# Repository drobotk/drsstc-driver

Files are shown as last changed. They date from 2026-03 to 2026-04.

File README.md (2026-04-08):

# DRSSTC driver

This is a KiCad project of the DRSSTC driver used in my tesla coil.

# Features:
- Single CT input for both clock and overcurrent detection
- Phase lead adjustable with a potentiometer, no need for a tunable inductor
- Adjustable self-oscillation, useful for testing and running a coil at the upper pole frequency
- Traditional / pulse skipping operation selectable with a jumper
- Adjustable UVLO for protecting precious IGBTs
- 74AHC high speed logic, less phase lead needed
- More modern parts than a UD2.7c

# Credits
As with most DRSSTC drivers, this one is based on previous work of many people (Steve Ward, Finn Hammer, Philip Slawinski, Bart Anderson, Eric Goodchild, Gao Guangyan, etc.). The design I took the most inspiration from is [this](https://highvoltageforum.net/index.php?topic=2054.0) project by [Mike](https://highvoltageforum.net/index.php?action=profile;u=1209) on HVF.

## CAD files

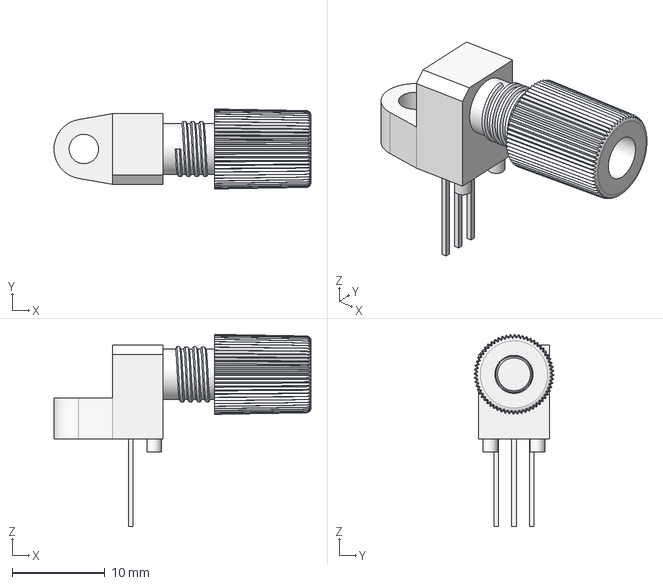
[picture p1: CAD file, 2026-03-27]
IF-D95T.stp
27.7 x 8.64 x 20.8 mm

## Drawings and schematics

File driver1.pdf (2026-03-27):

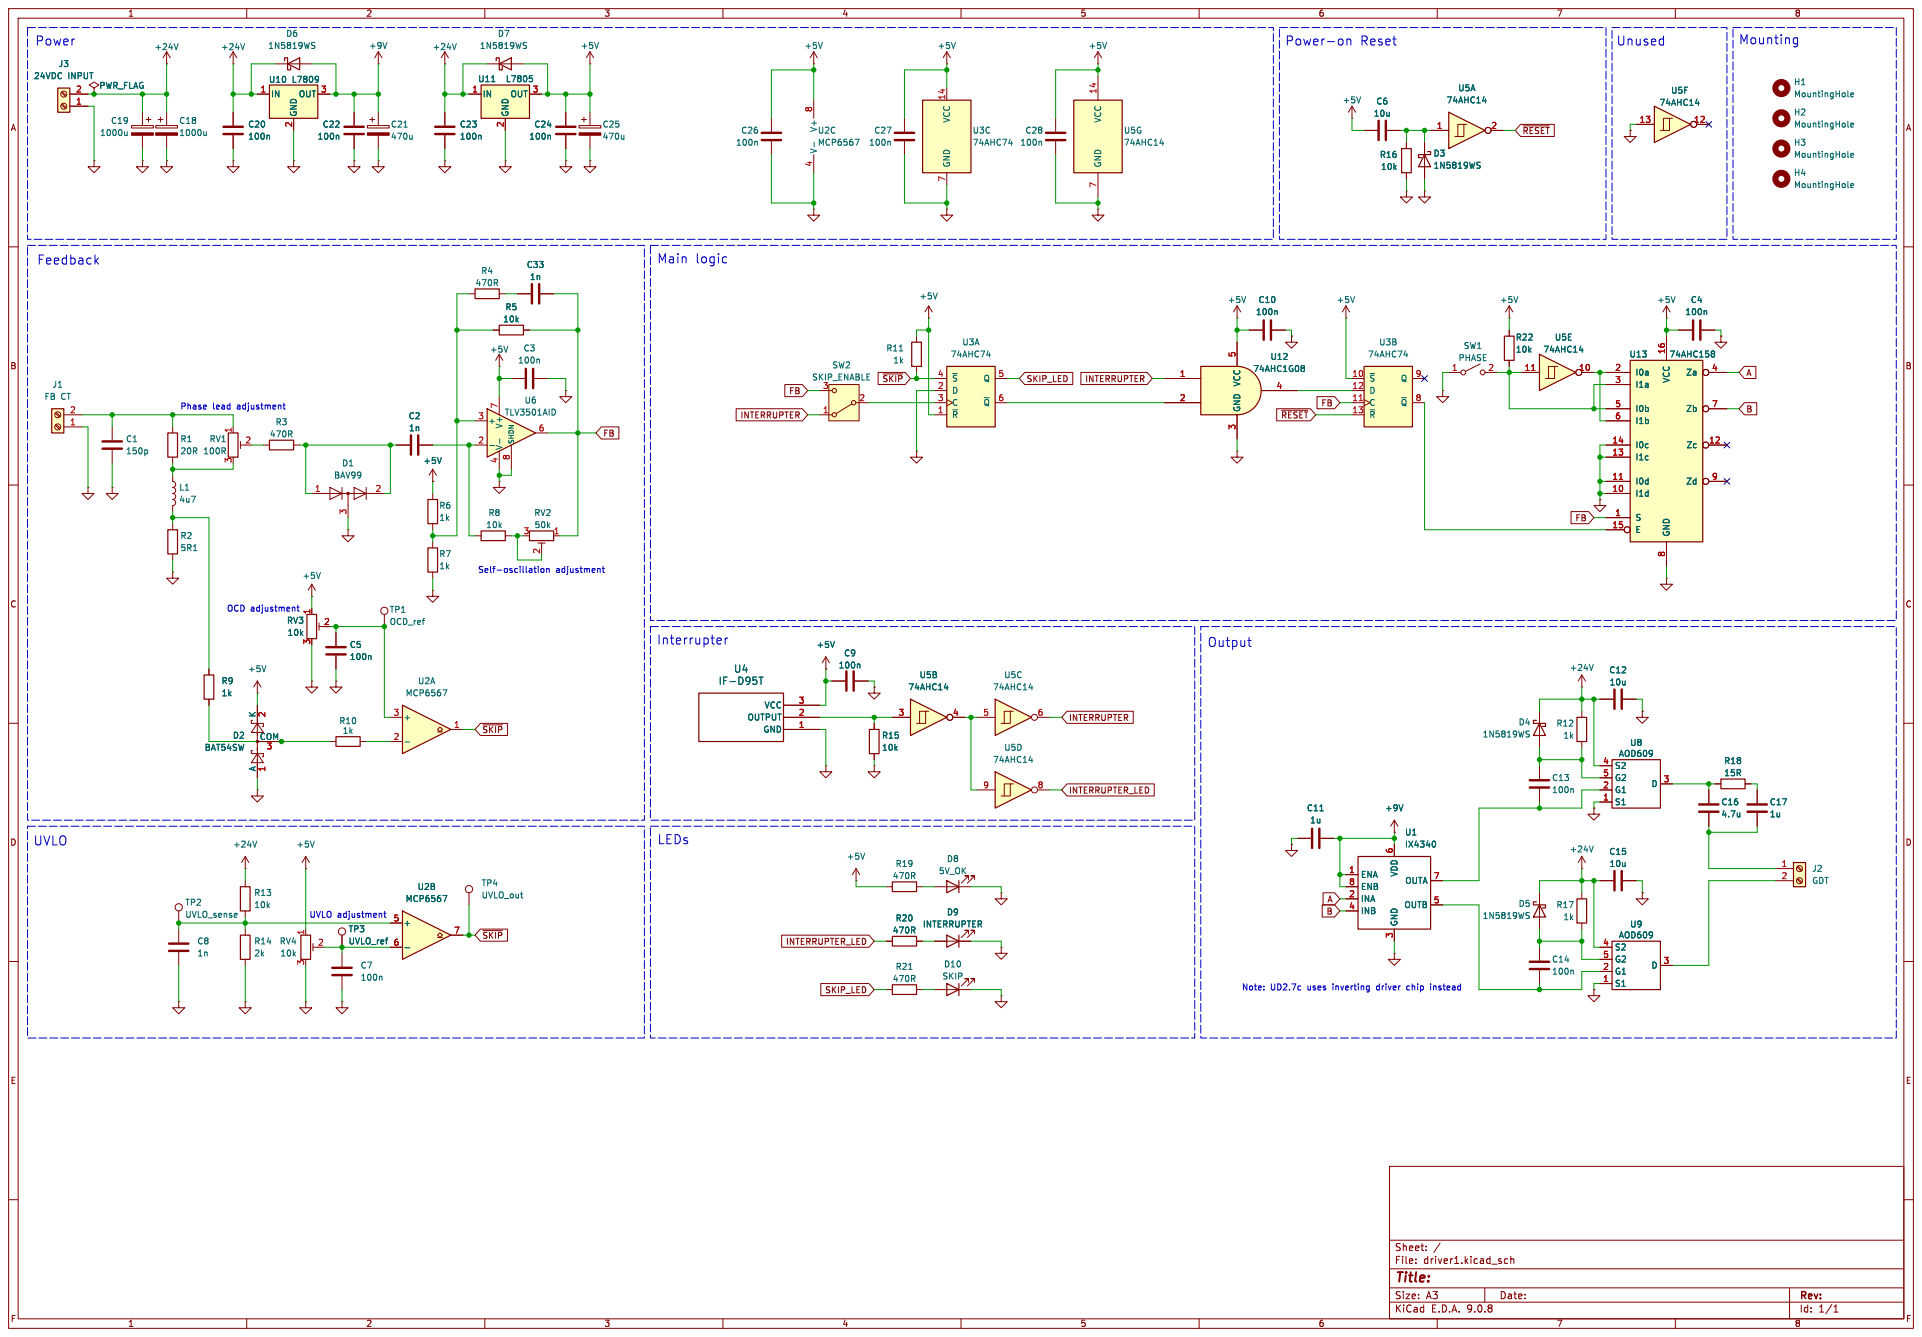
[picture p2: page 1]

Id: 1/1 Title: File: driver1.kicad_sch Sheet: /

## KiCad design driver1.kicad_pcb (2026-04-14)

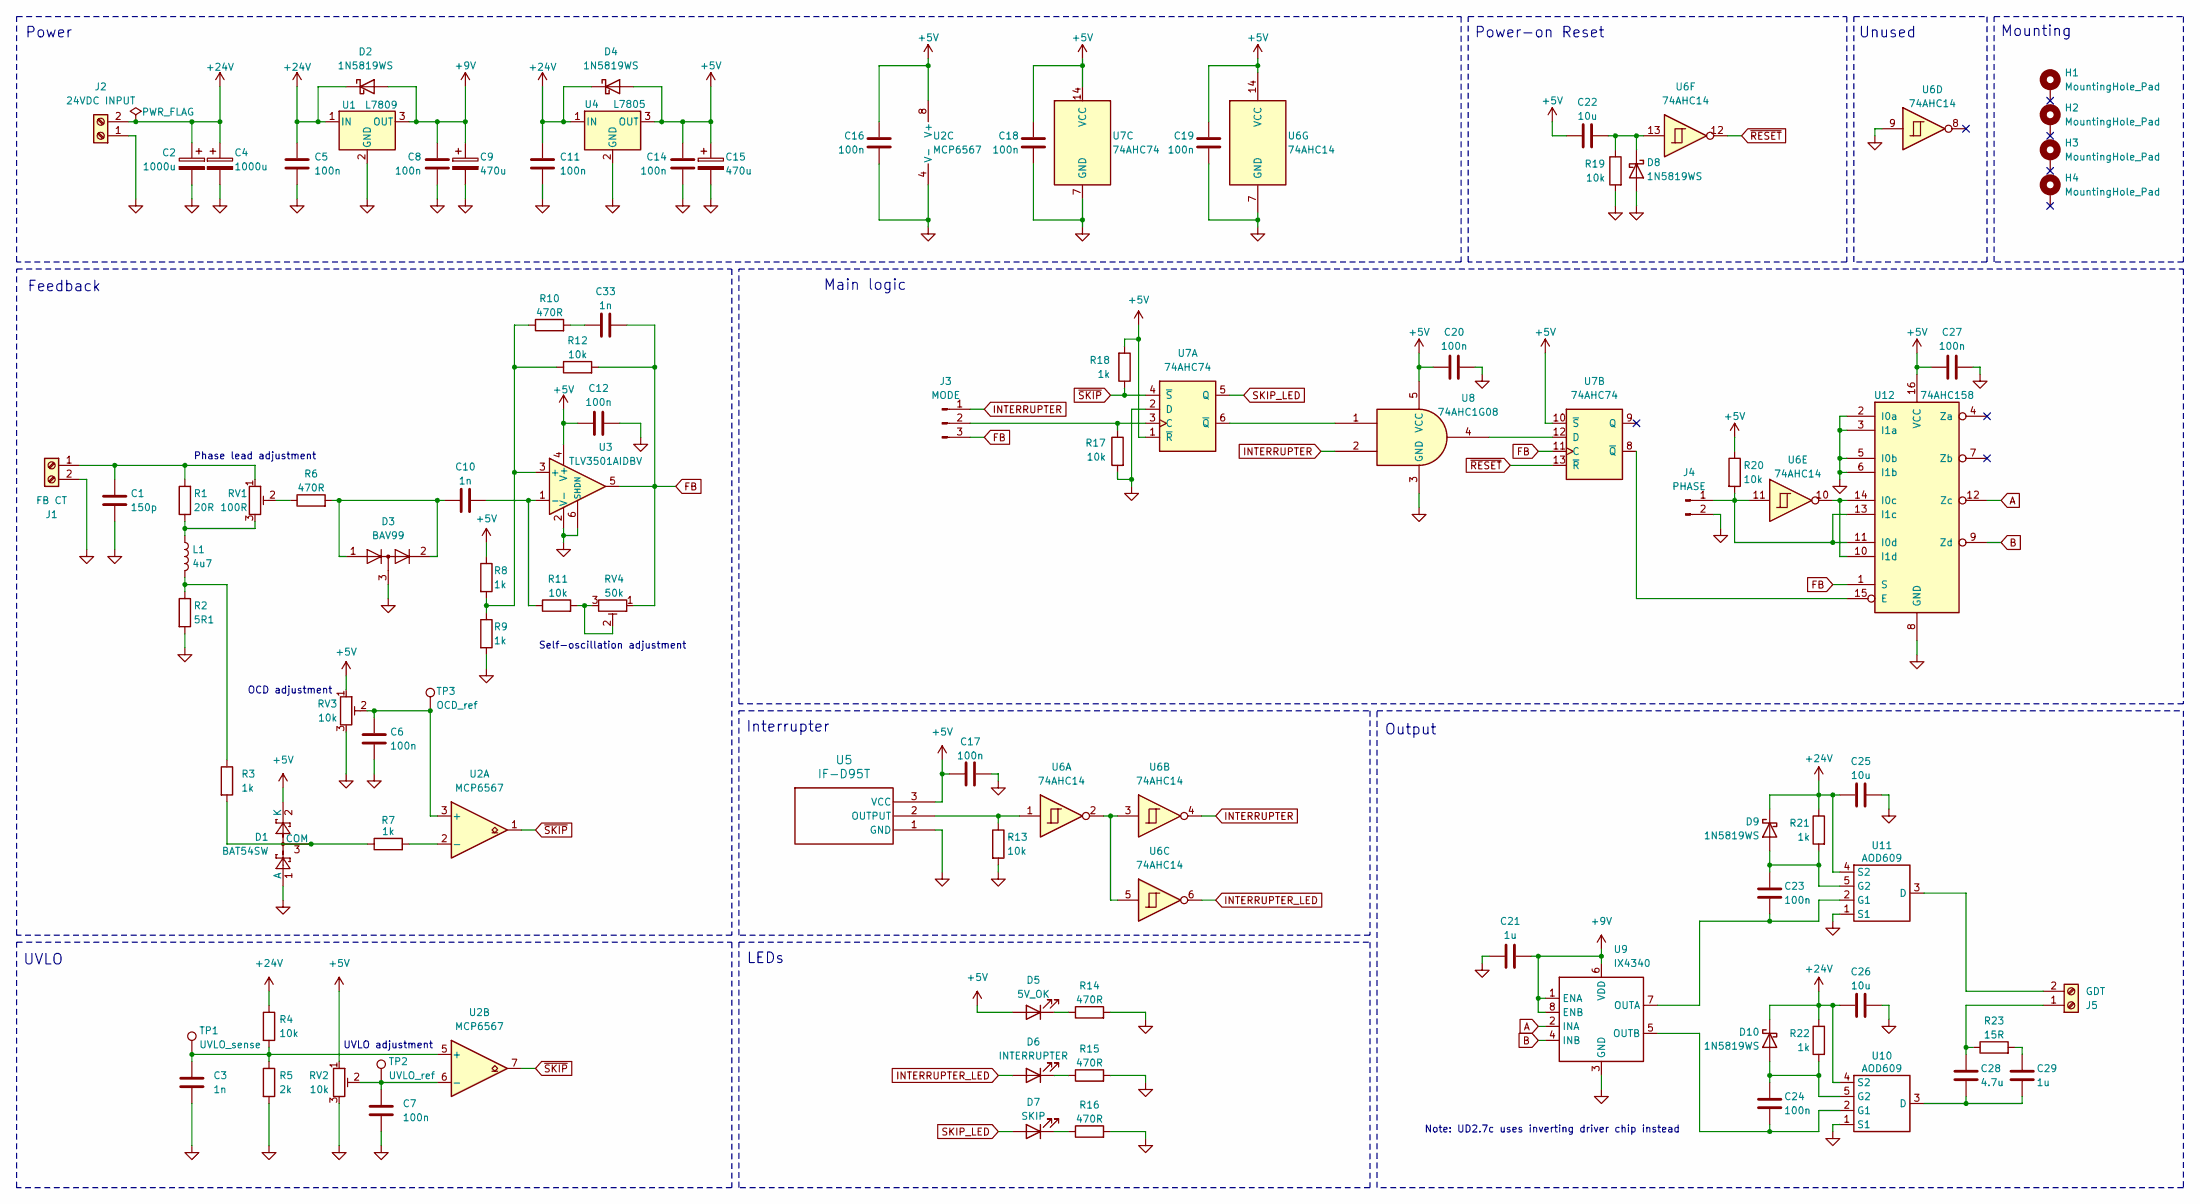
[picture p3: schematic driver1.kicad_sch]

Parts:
C1: 150p; C_0603_1608Metric_Pad1.08x0.95mm_HandSolder
C2, C4: 1000u; CP_Radial_D12.5mm_P5.00mm
C3, C10, C33: 1n; C_0603_1608Metric_Pad1.08x0.95mm_HandSolder
C5, C6, C7, C8, C11, C12, C14, C16, C17, C18, C19, C20, C27: 100n; C_0603_1608Metric_Pad1.08x0.95mm_HandSolder
C9, C15: 470u; CP_Radial_D8.0mm_P3.50mm
C21: 1u; C_0805_2012Metric_Pad1.18x1.45mm_HandSolder
C22, C25, C26: 10u; C_0805_2012Metric_Pad1.18x1.45mm_HandSolder
C23, C24: 100n; C_0805_2012Metric_Pad1.18x1.45mm_HandSolder
C28: 4.7u; C_1210_3225Metric_Pad1.33x2.70mm_HandSolder
C29: 1u; C_1210_3225Metric_Pad1.33x2.70mm_HandSolder
D1: BAT54SW; SOT-323_SC-70
D2, D4, D8, D9, D10: 1N5819WS; D_SOD-323
D3: BAV99; SOT-23
D5: 5V_OK; LED_D3.0mm
D6: INTERRUPTER; LED_D3.0mm
D7: SKIP; LED_D3.0mm
H1, H2, H3, H4: MountingHole_Pad; MountingHole_3.2mm_M3_Pad
J1: FB CT; Altech_AK100_1x02_P5.00mm
J2: 24VDC INPUT; Altech_AK100_1x02_P5.00mm
J3: MODE; PinHeader_1x03_P2.54mm_Vertical
J4: PHASE; PinHeader_1x02_P2.54mm_Vertical
J5: GDT; Altech_AK100_1x02_P5.00mm
L1: 4u7; L_Radial_D7.5mm_P3.50mm_Fastron_07P
R1: 20R; R_2512_6332Metric_Pad1.40x3.35mm_HandSolder
R2: 5R1; R_1210_3225Metric_Pad1.30x2.65mm_HandSolder
R3, R7, R8, R9, R18, R21, R22: 1k; R_0603_1608Metric_Pad0.98x0.95mm_HandSolder
R4, R11, R12, R13, R17, R19, R20: 10k; R_0603_1608Metric_Pad0.98x0.95mm_HandSolder
R5: 2k; R_0603_1608Metric_Pad0.98x0.95mm_HandSolder
R6, R10, R14, R15, R16: 470R; R_0603_1608Metric_Pad0.98x0.95mm_HandSolder
R23: 15R; R_1210_3225Metric_Pad1.30x2.65mm_HandSolder
RV1: 100R; Potentiometer_Bourns_3296W_Vertical
RV2, RV3: 10k; Potentiometer_Bourns_3296W_Vertical
RV4: 50k; Potentiometer_Bourns_3296W_Vertical
TP1: UVLO_sense; TestPoint_Pad_D2.0mm
TP2: UVLO_ref; TestPoint_Pad_D2.0mm
TP3: OCD_ref; TestPoint_Pad_D2.0mm
U1: L7809; TO-252-2
U2: MCP6567; MSOP-8_3x3mm_P0.65mm
U3: TLV3501AIDBV; SOT-23-6
U4: L7805; TO-252-2
U5: IF-D95T; IF-D95T_IFB
U6: 74AHC14; TSSOP-14_4.4x5mm_P0.65mm
U7: 74AHC74; TSSOP-14_4.4x5mm_P0.65mm
U8: 74AHC1G08; SOT-353_SC-70-5
U9: IX4340; SOIC-8_3.9x4.9mm_P1.27mm
U10, U11: AOD609; TO-252-4
U12: 74AHC158; TSSOP-16_4.4x5mm_P0.65mm

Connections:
+5V: C12.2, C14.1, C15.1, C16.2, C17.1, C18.2, C19.2, C20.1, C22.1, C27.1, D1.2 (K), D4.2 (A), D5.2 (A), R8.1, R18.2, R20.1, RV2.1, RV3.1, U2.8 (V+), U3.4 (V+), U4.3 (OUT), U5.3 (VCC), U6.14 (VCC), U7.1 (~R), U7.10 (~S), U7.14 (VCC), U8.5 (VCC), U12.16 (VCC)
+9V: C8.1, C9.1, C21.2, D2.2 (A), U1.3 (OUT), U9.1 (ENA), U9.6 (VDD), U9.8 (ENB)
+24V: C2.1, C4.1, C5.1, C11.1, C25.1, C26.1, D2.1 (K), D4.1 (K), D9.1 (K), D10.1 (K), J2.2, R4.1, R21.1, R22.1, U1.1 (IN), U4.1 (IN), U10.4 (S2), U11.4 (S2)
A: U9.2 (INA), U12.12 (Zc)
B: U9.4 (INB), U12.9 (Zd)
FB: C33.2, J3.3, R12.2, RV4.1, U3.5, U7.11 (C), U12.1 (S)
GND: C1.2, C2.2, C3.2, C4.2, C5.2, C6.2, C7.2, C8.2, C9.2, C11.2, C12.1, C14.2, C15.2, C16.1, C17.2, C18.1, C19.1, C20.2, C21.1, C25.2, C26.2, C27.2, D1.1 (A), D3.3 (K), D8.2 (A), J1.2, J2.1, J4.2, R2.2, R5.2, R9.2, R13.2, R14.2, R15.2, R16.2, R17.2, R19.2, RV2.3, RV3.3, U1.2 (GND), U2.4 (V-), U3.2 (V-), U3.6 (SHDN), U4.2 (GND), U5.1 (GND), U6.7 (GND), U6.9, U7.2 (D), U7.7 (GND), U8.3 (GND), U9.3 (GND), U10.1 (S1), U11.1 (S1), U12.2 (I0a), U12.3 (I1a), U12.5 (I0b), U12.6 (I1b), U12.8 (GND)
INTERRUPTER: J3.1, U6.4, U8.2
INTERRUPTER_LED: D6.2 (A), U6.6
unnamed: C29.1, R23.2
unnamed: C33.1, R10.2
unnamed: D1.3 (COM), R3.2, R7.1
unnamed: C10.1, D3.1 (K), D3.2 (A), R6.2
unnamed: D5.1 (K), R14.1
unnamed: D6.1 (K), R15.1
unnamed: D7.1 (K), R16.1
unnamed: C22.2, D8.1 (K), R19.1, U6.13
unnamed: C23.1, D9.2 (A), R21.2, U11.5 (G2)
unnamed: C24.1, D10.2 (A), R22.2, U10.5 (G2)
unnamed: C1.1, J1.1, R1.2, RV1.1
unnamed: J3.2, R17.1, U7.3 (C)
unnamed: J4.1, R20.2, U6.11, U12.11 (I0d), U12.13 (I1c)
unnamed: C28.1, J5.1, R23.1
unnamed: J5.2, U11.3 (D)
unnamed: L1.1, R1.1, RV1.3
unnamed: L1.2, R2.1, R3.1
unnamed: R6.1, RV1.2
unnamed: R11.2, RV4.2, RV4.3
unnamed: C6.1, RV3.2, TP3.1 (1_1), U2.3 (+)
unnamed: R7.2, U2.2 (-)
unnamed: C3.1, R4.2, R5.1, TP1.1 (1_1), U2.5 (+)
unnamed: C7.1, RV2.2, TP2.1 (1_1), U2.6 (-)
unnamed: R8.2, R9.1, R10.1, R12.1, U3.3 (+)
unnamed: C10.2, R11.1, U3.1 (-)
unnamed: R13.1, U5.2 (OUTPUT), U6.1
unnamed: U6.2, U6.3, U6.5
unnamed: U7.6 (~Q), U8.1
unnamed: U7.12 (D), U8.4
unnamed: C28.2, C29.2, U10.3 (D)
unnamed: C24.2, U9.5 (OUTB), U10.2 (G1)
unnamed: C23.2, U9.7 (OUTA), U11.2 (G1)
unnamed: U7.8 (~Q), U12.15 (E)
unnamed: U6.10, U12.10 (I1d), U12.14 (I0c)
SKIP_LED: D7.2 (A), U7.5 (Q)
~RESET: U6.12, U7.13 (~R)
~SKIP: R18.1, U2.1, U2.7, U7.4 (~S)

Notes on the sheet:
Interrupter
Self-oscillation adjustment
Power
Unused
OCD adjustment
UVLO adjustment
UVLO
Power-on Reset
LEDs
Main logic
Phase lead adjustment
Note: UD2.7c uses inverting driver chip instead
Output
Feedback
Mounting

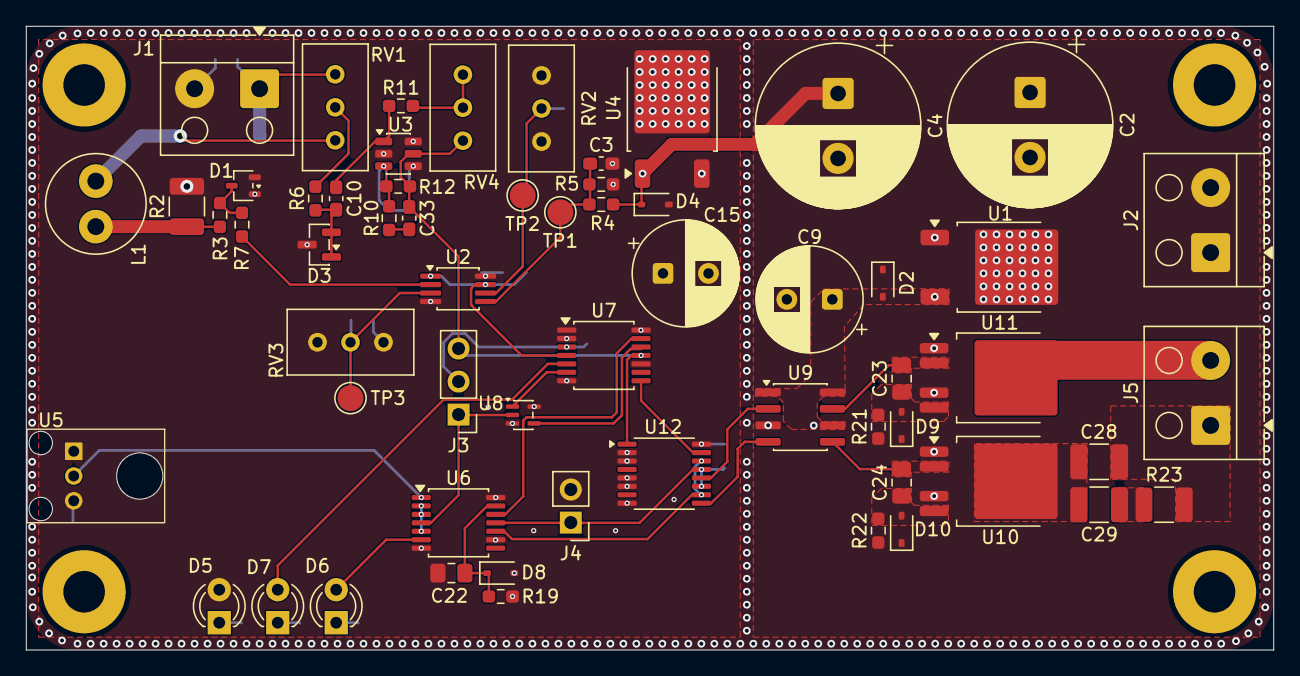
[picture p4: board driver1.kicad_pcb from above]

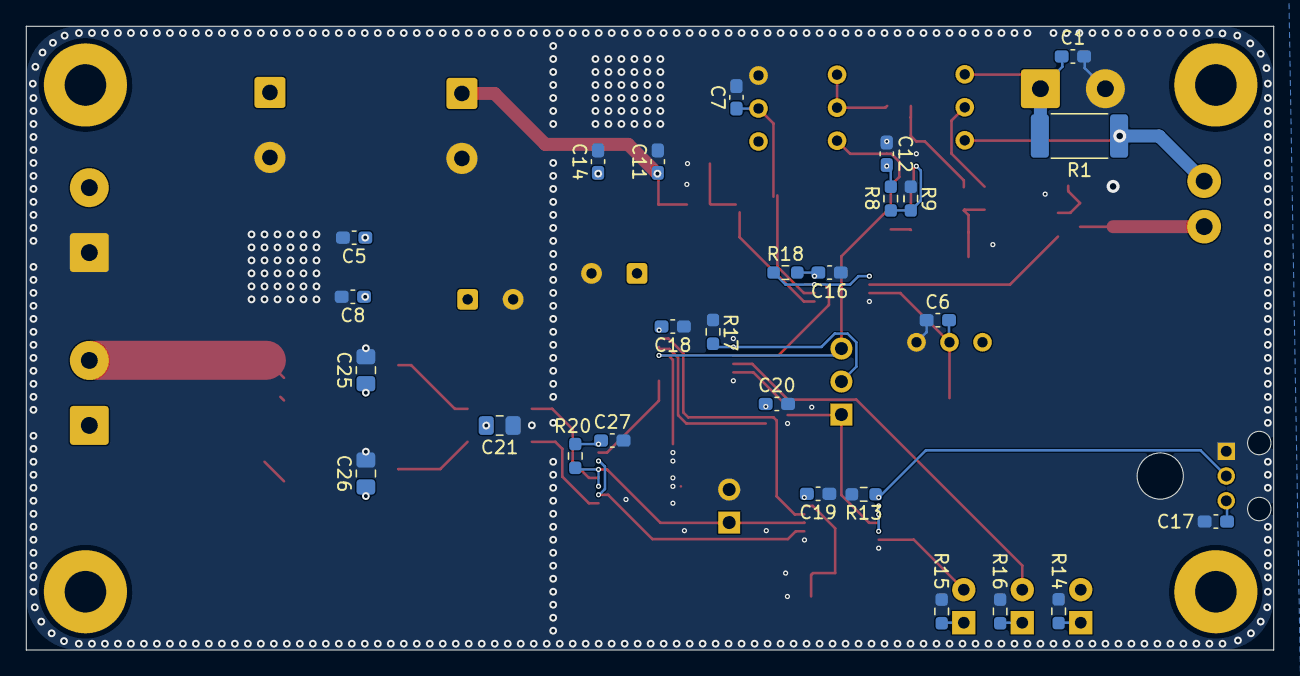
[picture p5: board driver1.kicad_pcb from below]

Board: 2 copper layers, 96.0 x 48.0 mm, 91 parts (27 on the bottom side), 46 nets.

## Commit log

2026-03-27 Fix footprint link
    [driver1.kicad_sch]
2026-04-01 pcb progress
    [driver1.kicad_pcb, driver1.kicad_sch]
2026-04-08 baby steps
    [driver1.kicad_pcb, driver1.kicad_sch]
2026-04-09 almost done
    [driver1.kicad_pcb, driver1.kicad_sch]
2026-04-09 infant steps
    [driver1.kicad_pcb]
2026-04-10 the wheels on the bus go round and round
    [driver1.kicad_pcb]
2026-04-14 i hate zones
    [driver1.kicad_pcb]
